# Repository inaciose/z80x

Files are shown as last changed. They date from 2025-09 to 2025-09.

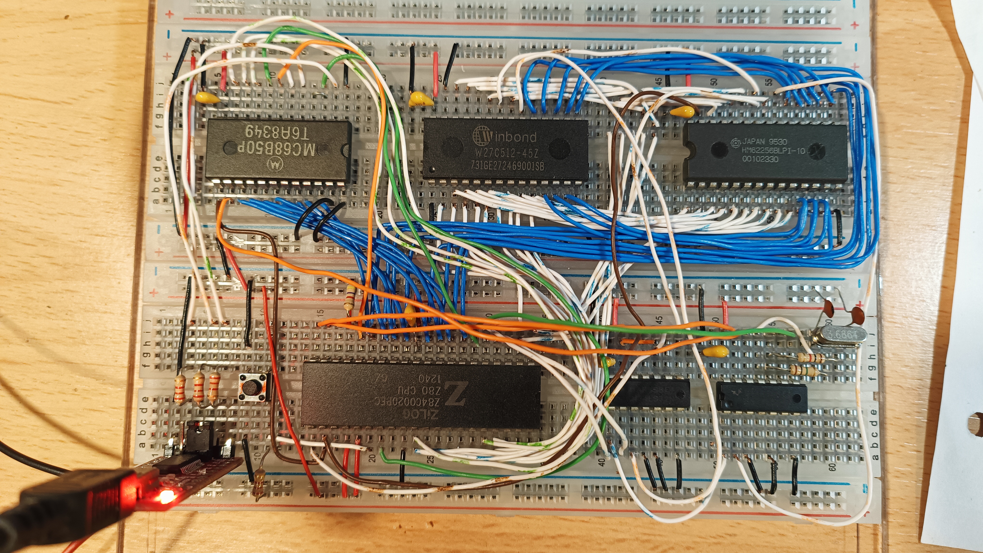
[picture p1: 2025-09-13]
Z80_SBC1/breadboard.jpg

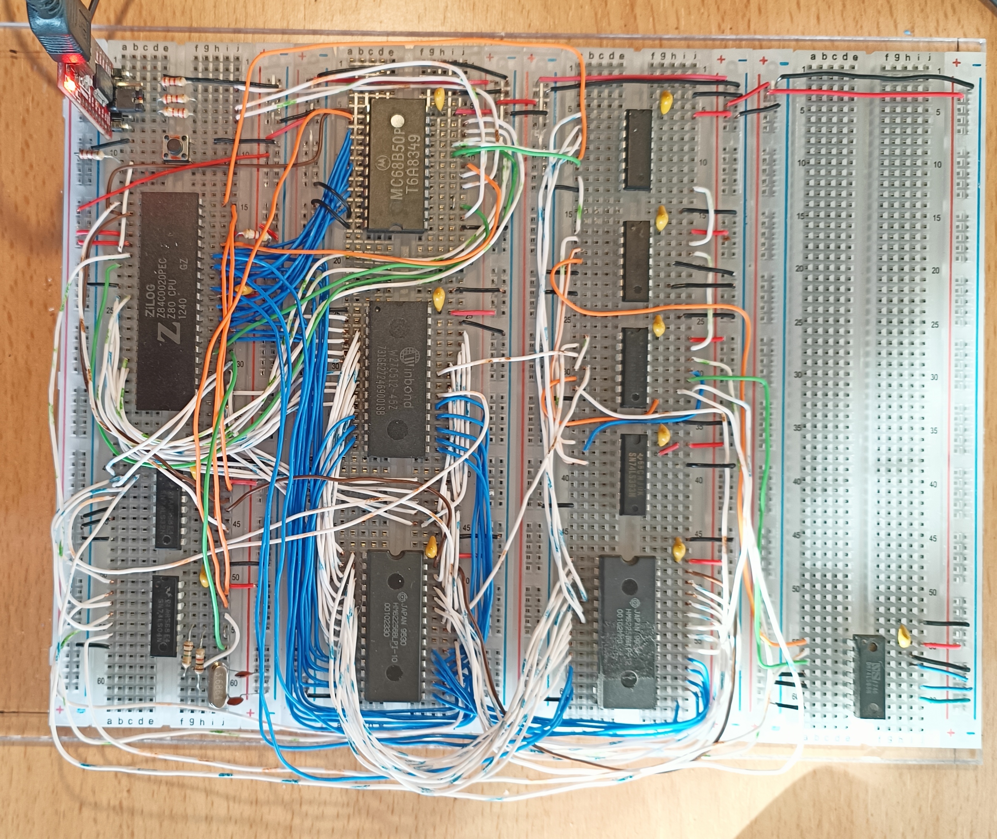
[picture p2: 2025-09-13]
Z80_SBC2/breadboard.jpg

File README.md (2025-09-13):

# z80x
SBCs &amp; MBCs and other Z80 explorations    

# Z80_SBC1
3.6864Mz, 16KB ROM, 32K RAM and serial MC68B50 (0x80) 57600bps (115200 c/ o dobro do relógio)  

ROM 9B000000.BIN with (RC2014 versions):  
- SCM-Small Computer Monitor  
- MS-BASIC  

# Z80_SBC2
3.6864Mz, 16KB (0KB paged) ROM, 48KB (64KB paged) RAM and serial MC68B50 (0x80) 57600bps  
Pageable ROM/RAML16K (0x38 toggle page, 0x30 reset page)  

Same ROM as Z80_SBC1 (or the one with CP/M 2.2 bootloader ?)

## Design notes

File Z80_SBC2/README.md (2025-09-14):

# Z80_SBC2

3.6864Mz, 16KB (0KB paged) ROM, 48KB (64KB paged) RAM and serial MC68B50 (0x80) 57600bps 8N1  
Pageable ROM/RAML16K (0x38 toggle page, 0x30 reset page)  

Same ROM as Z80_SBC1: 9B000000.BIN; (or the one with CP/M 2.2 bootloader ?)  

Press reset after power on (the reset circuit must be revised)
Help (commands): help  
MS-BASIC: G 2000  
Exit MS-BASIC: monitor  

# Page ROM

Copy ROM to RAM  
Load rom2ram.z80.hex file contents    
G 8000  

Toogle PAGE  
o 38 HH  

Reset PAGE  
o 30 HH  

# Equations  
MEMRD = MREQ_ + RD_  
MEMWR = MREQ_ + WR_  

PAGE = Q0 of 74LS393 counter with COUNTER_CLK via port 0x38, and COUNTER_RESET via port 0x30 or RESET  

ROM_CE = A14 + A15  
ROM_OE = PAGE + MEMRD  

RAML_CE = A15  
RAML_OE = A15 + (not(A14) x not(PAGE)) + MEMRD  
RAMH_WE = MEMWR  

RAMH_CE = not(A15)  
RAMH_OE = MEMRD  
RAMH_WE = MEMWR  

# Truth table for RAML_OE  
MR = MEMRD  

M A A P Y  
R 1 1 A  
  5 4 G  
      E  
0 0 0 0 1  
0 0 0 1 0 > MR + A15 + A14 + not(PAGE)  
0 0 1 0 0 > MR + A15 + not(A14) + PAGE  
0 0 1 1 0 > MR + A15 + not(A14) + not(PAGE)  
0 1 0 0 1  
0 1 0 1 1  
0 1 1 0 1  
0 1 1 1 1  
0 0 0 0 1  
0 0 0 1 1  
0 0 1 0 1  
0 0 1 1 1  
0 1 0 0 1  
0 1 0 1 1  
0 1 1 0 1  
0 1 1 1 1  

RAML_OE = (MR + A15 + A14 + not(PAGE)) x (MR + A15 + not(A14) + PAGE) x (MR + A15 + not(A14) + not(PAGE))  

Simplificado, fica: RAML_OE = A15 + (not(A14) x not(PAGE)) + MEMRD  

Com ROM 8K ???:  
ROM_CE = A13 + A14 + A15 (no IC: A15-GND, A14-GND, A13-GND)  
RAML_OE = A15 + (not(A13) x not(PAGE)) + MEMRD  

# Notes
Based on Z80_SBC1, and part of the RC2014 Pageable ROM (74LS138, 74LS393 and its input logic) with some more required logic.  
https://rc2014.co.uk/modules/pageable-rom/

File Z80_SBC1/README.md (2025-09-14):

# Z80_SBC1

3.6864Mz, 16KB ROM, 32K RAM and serial MC68B50 (0x80) 57600bps 8N1 (115200 c/ o dobro do relógio)  

ROM 9B000000.BIN with (RC2014 versions):  
- 0000-1FFF: SCM-Small Computer Monitor  
- 2000-3FFF: MS-BASIC  

Press reset after power on (the reset circuit must be revised)

Help (commands): help  
MS-BASIC: G 2000  
Exit MS-BASIC: monitor  

# Equations  
MEMRD = MREQ_ + RD_  
MEMWR = MREQ_ + WR_  

ROM_CE = A14 + A15  
ROM_OE = MEMRD  

RAM_CE = not(A15)  
RAM_OE = MEMRD  
RAM_WE = MEMWR  

ACIA = A7 x not(A6) (10XX XXXX, 0x80 com replicas, RC2014 MC68B50 serial module)  

# Notes
Based on Searle Grants Minimal Z80 with 8KB ROM, 32K RAM and serial MC68B50.  
http://searle.x10host.com/z80/SimpleZ80_32K.html

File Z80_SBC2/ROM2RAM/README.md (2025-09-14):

# ROM2RAM

Copy the 16KB ROM contents to the first 16KB of RAM (while ROM still paged in).  

In minicom:  
sudo minicom -c on --device /dev/ttyUSB0  

Copy rom2ram.z80.hex contents and past it to SCM prompt  

Wait for:  
*Ready  

*  
then type:  
G 8000  

ROM contents copied to RAM. Now we can toogle ROM (PAGE) in/out by writing to 0x38 or reset PAGE (PAGE=0) by writing to 0x30.  

74LS393:Q0 = PAGE  

PAGE = 0: ROM in, RAMLL out;  
PAGE = 1: ROM out, RAMLL in;  

Toggle PAGE  
o 38 0  

Reset PAGE  
o 30 0  

# Assembler
Assembly for the asm80, the z80 assembler online.  
https://www.asm80.com/

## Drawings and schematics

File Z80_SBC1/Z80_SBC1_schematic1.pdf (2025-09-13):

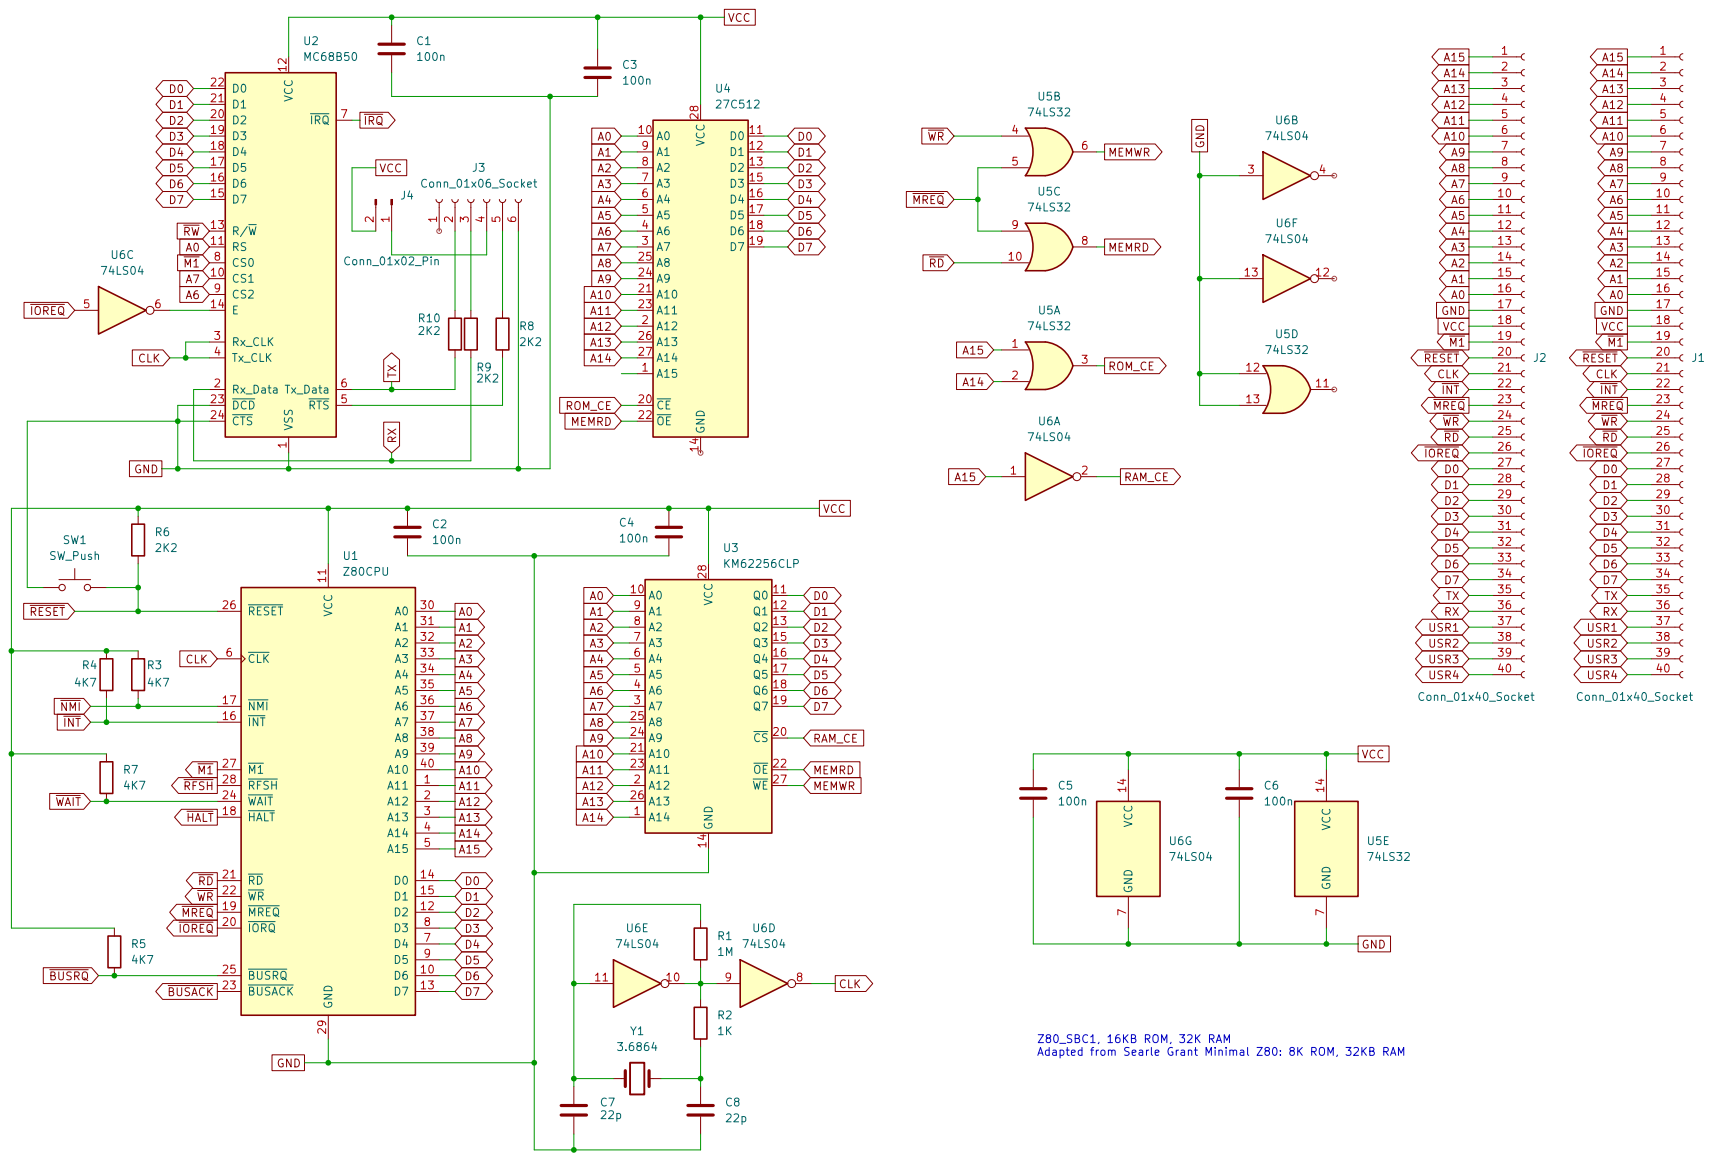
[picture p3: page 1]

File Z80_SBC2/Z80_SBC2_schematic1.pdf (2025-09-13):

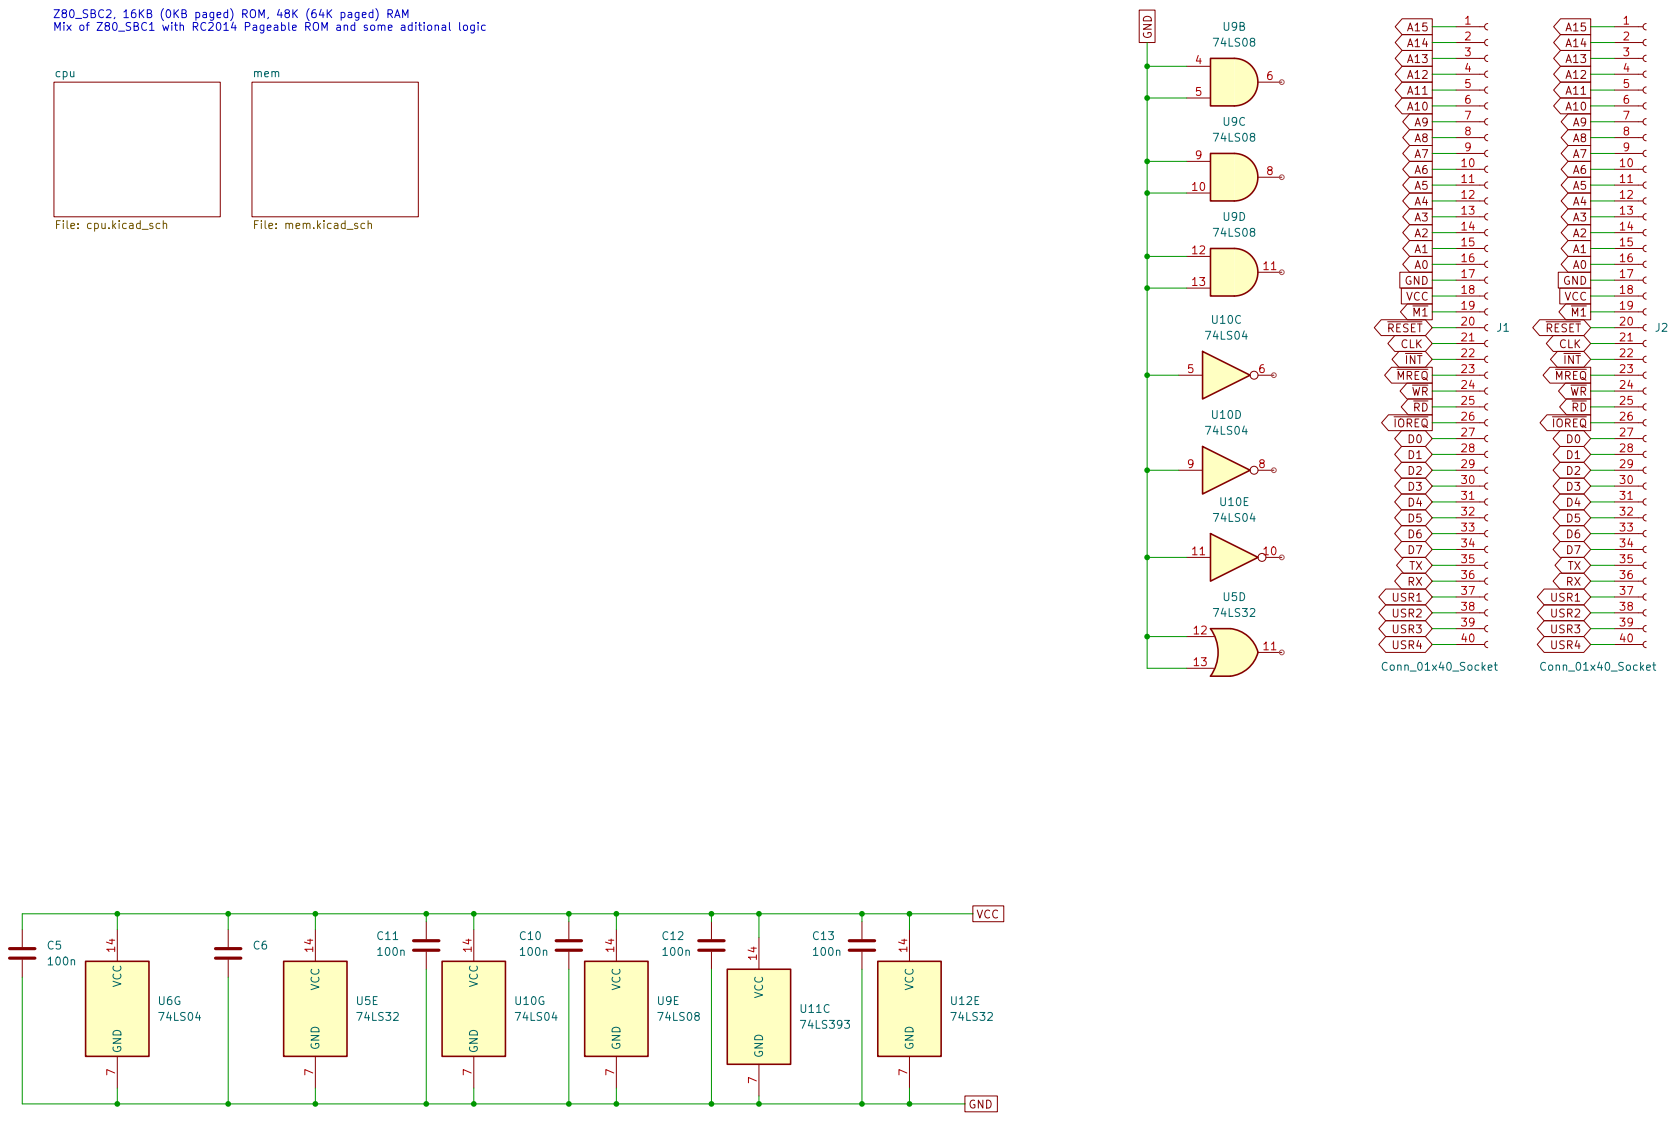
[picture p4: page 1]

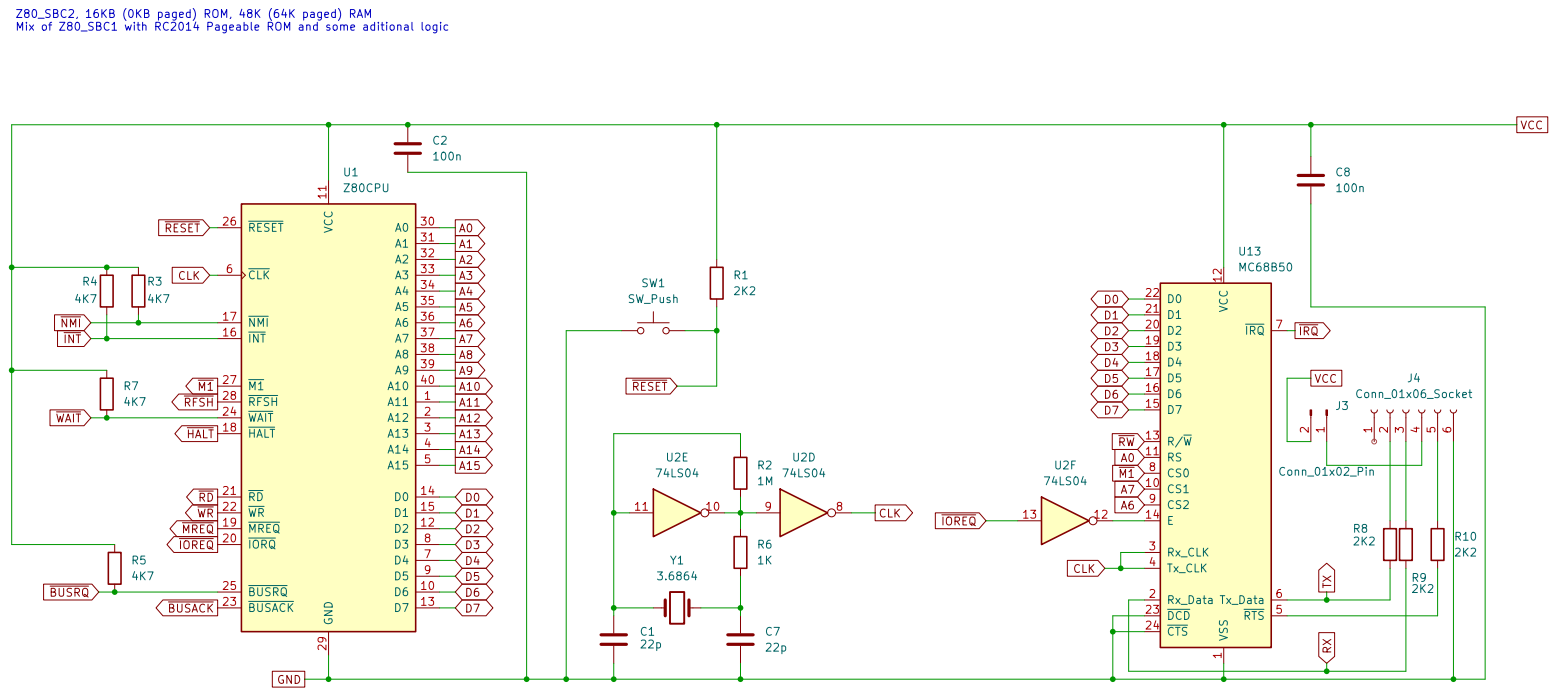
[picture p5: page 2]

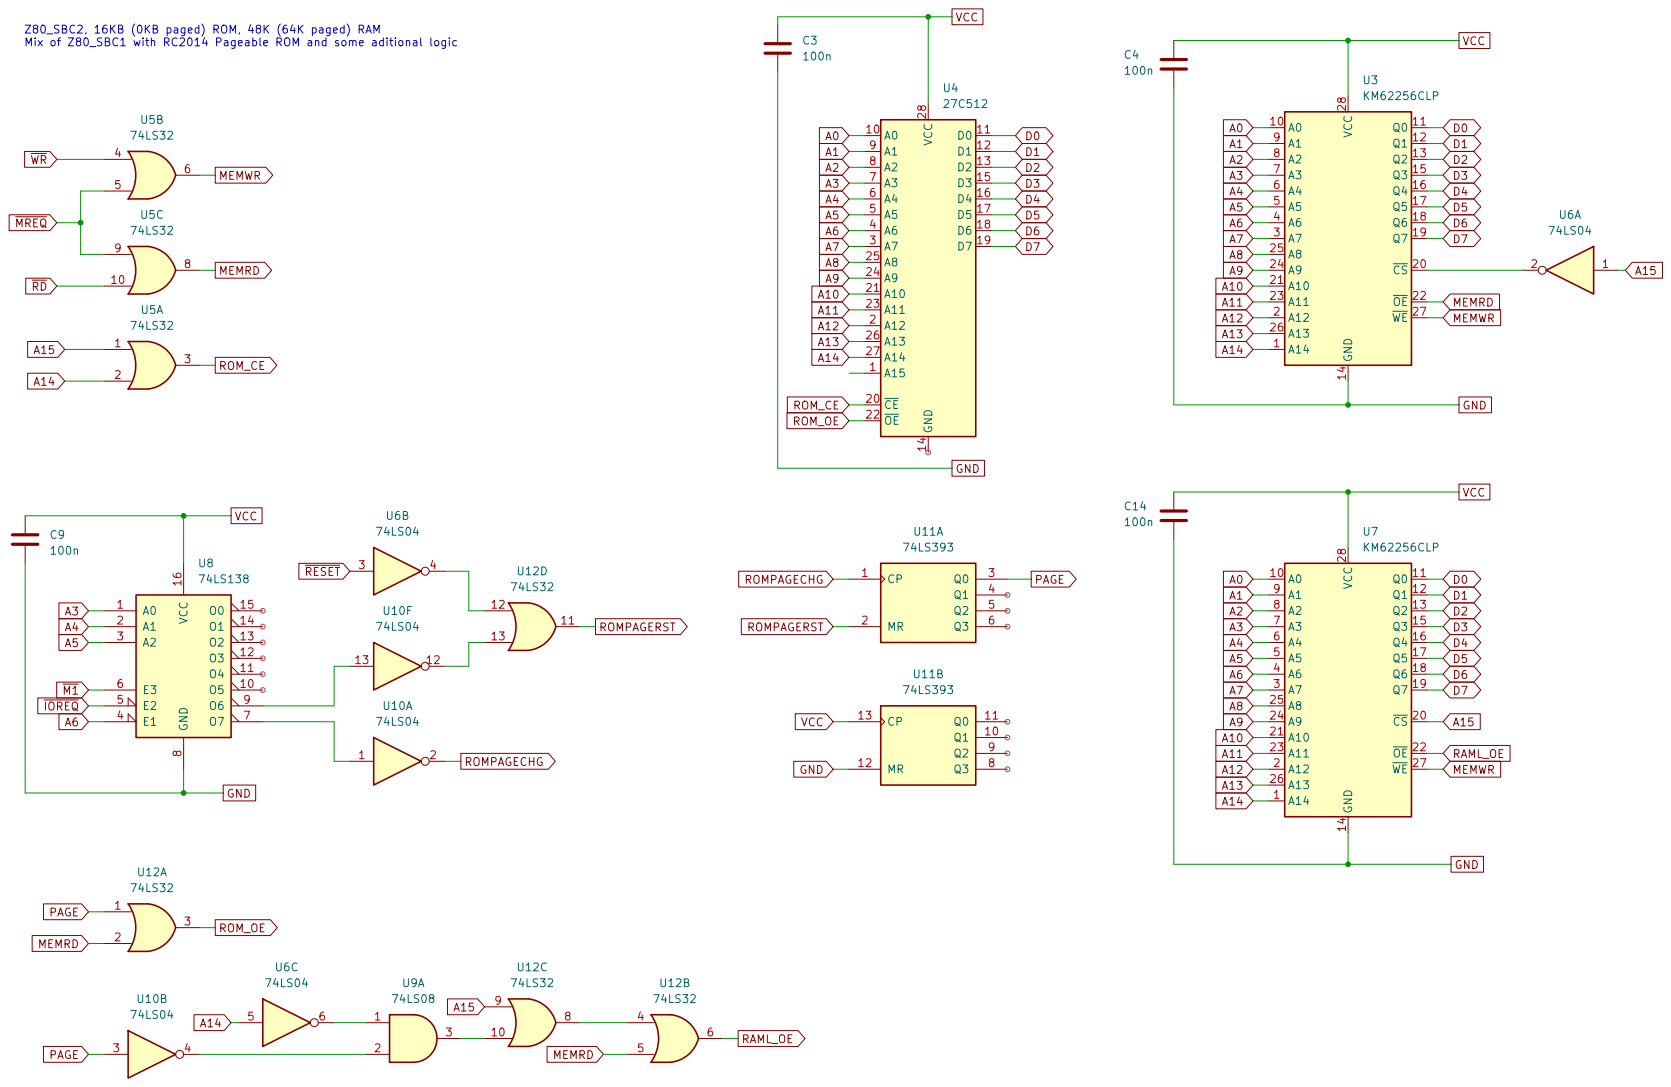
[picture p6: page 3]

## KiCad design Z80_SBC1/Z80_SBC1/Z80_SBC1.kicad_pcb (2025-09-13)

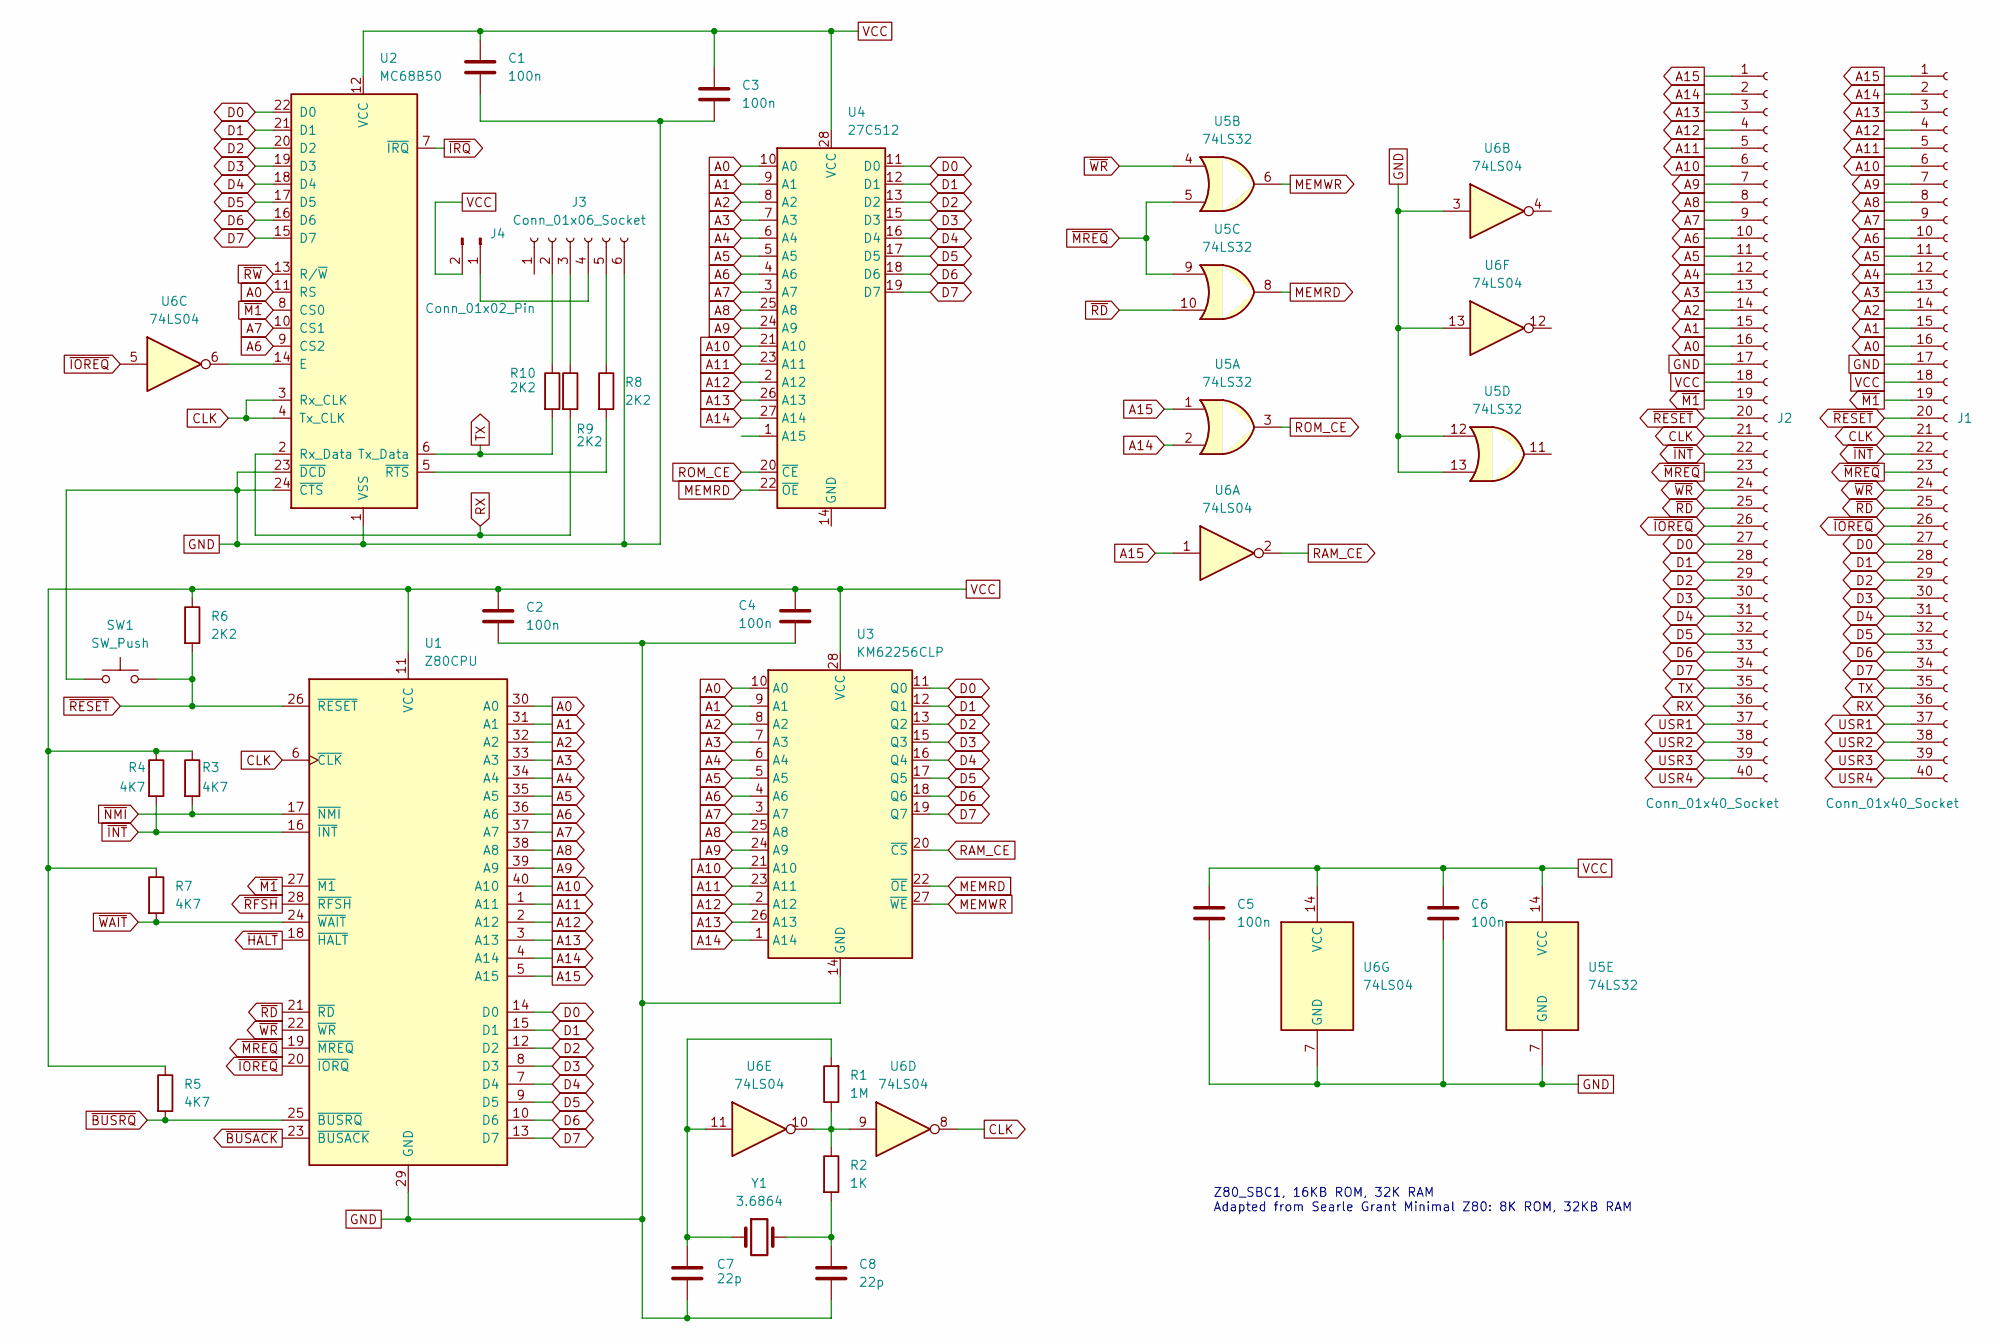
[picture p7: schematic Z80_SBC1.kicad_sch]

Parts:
C1, C2, C3, C4, C5, C6: 100n; C_Disc_D5.1mm_W3.2mm_P5.00mm
C7, C8: 22p; C_Disc_D3.0mm_W2.0mm_P2.50mm
J1: Conn_01x40_Socket; PinHeader_1x40_P2.54mm_Horizontal
J2: Conn_01x40_Socket; PinHeader_1x40_P2.54mm_Vertical
J3: Conn_01x06_Socket; PinHeader_1x06_P2.54mm_Horizontal
J4: Conn_01x02_Pin; PinHeader_1x02_P2.54mm_Vertical
R1: 1M; R_Axial_DIN0207_L6.3mm_D2.5mm_P7.62mm_Horizontal
R2: 1K; R_Axial_DIN0207_L6.3mm_D2.5mm_P7.62mm_Horizontal
R3, R4, R5, R7: 4K7; R_Axial_DIN0207_L6.3mm_D2.5mm_P7.62mm_Horizontal
R6, R8, R9, R10: 2K2; R_Axial_DIN0207_L6.3mm_D2.5mm_P7.62mm_Horizontal
SW1: SW_Push; SW_Tactile_Straight_KSA0Axx1LFTR
U1: Z80CPU; DIP-40_W15.24mm_Socket_LongPads
U2: MC68B50; DIP-24_W15.24mm
U3: KM62256CLP; DIP-28_W15.24mm
U4: 27C512; DIP-28_W15.24mm
U5: 74LS32; DIP-14_W7.62mm_LongPads
U6: 74LS04; DIP-14_W7.62mm_LongPads
Y1: 3.6864; Crystal_HC18-U_Vertical

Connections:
A0: J1.16, J2.16, U1.30 (A0), U2.11 (RS), U3.10 (A0), U4.10 (A0)
A1: J1.15, J2.15, U1.31 (A1), U3.9 (A1), U4.9 (A1)
A2: J1.14, J2.14, U1.32 (A2), U3.8 (A2), U4.8 (A2)
A3: J1.13, J2.13, U1.33 (A3), U3.7 (A3), U4.7 (A3)
A4: J1.12, J2.12, U1.34 (A4), U3.6 (A4), U4.6 (A4)
A5: J1.11, J2.11, U1.35 (A5), U3.5 (A5), U4.5 (A5)
A6: J1.10, J2.10, U1.36 (A6), U2.9 (CS2), U3.4 (A6), U4.4 (A6)
A7: J1.9, J2.9, U1.37 (A7), U2.10 (CS1), U3.3 (A7), U4.3 (A7)
A8: J1.8, J2.8, U1.38 (A8), U3.25 (A8), U4.25 (A8)
A9: J1.7, J2.7, U1.39 (A9), U3.24 (A9), U4.24 (A9)
A10: J1.6, J2.6, U1.40 (A10), U3.21 (A10), U4.21 (A10)
A11: J1.5, J2.5, U1.1 (A11), U3.23 (A11), U4.23 (A11)
A12: J1.4, J2.4, U1.2 (A12), U3.2 (A12), U4.2 (A12)
A13: J1.3, J2.3, U1.3 (A13), U3.26 (A13), U4.26 (A13)
A14: J1.2, J2.2, U1.4 (A14), U3.1 (A14), U4.27 (A14), U5.2
A15: J1.1, J2.1, U1.5 (A15), U5.1, U6.1
CLK: J1.21, J2.21, U1.6 (~CLK), U2.3 (Rx_CLK), U2.4 (Tx_CLK), U6.8
D0: J1.27, J2.27, U1.14 (D0), U2.22 (D0), U3.11 (Q0), U4.11 (D0)
D1: J1.28, J2.28, U1.15 (D1), U2.21 (D1), U3.12 (Q1), U4.12 (D1)
D2: J1.29, J2.29, U1.12 (D2), U2.20 (D2), U3.13 (Q2), U4.13 (D2)
D3: J1.30, J2.30, U1.8 (D3), U2.19 (D3), U3.15 (Q3), U4.15 (D3)
D4: J1.31, J2.31, U1.7 (D4), U2.18 (D4), U3.16 (Q4), U4.16 (D4)
D5: J1.32, J2.32, U1.9 (D5), U2.17 (D5), U3.17 (Q5), U4.17 (D5)
D6: J1.33, J2.33, U1.10 (D6), U2.16 (D6), U3.18 (Q6), U4.18 (D6)
D7: J1.34, J2.34, U1.13 (D7), U2.15 (D7), U3.19 (Q7), U4.19 (D7)
GND: C1.2, C2.2, C3.2, C4.2, C5.2, C6.2, C7.2, C8.2, J1.17, J2.17, J3.6, SW1.1, U1.29 (GND), U2.1 (VSS), U2.23 (~DCD), U2.24 (~CTS), U3.14 (GND), U5.7 (GND), U5.12, U5.13, U6.3, U6.7 (GND), U6.13
MEMRD: U3.22 (~OE), U4.22 (~OE), U5.8
MEMWR: U3.27 (~WE), U5.6
unnamed: C7.1, R1.2, U6.11, Y1.1
unnamed: C8.1, R2.2, Y1.2
unnamed: J3.2, R10.1
unnamed: J3.3, R9.1
unnamed: J3.4, J4.1
unnamed: J3.5, R8.1
unnamed: R1.1, R2.1, U6.9, U6.10
unnamed: U2.14 (E), U6.6
unnamed: R8.2, U2.5 (~RTS)
RAM_CE: U3.20 (~CS), U6.2
ROM_CE: U4.20 (~CE), U5.3
RX: J1.36, J2.36, R9.2, U2.2 (Rx_Data)
TX: J1.35, J2.35, R10.2, U2.6 (Tx_Data)
USR1: J1.37, J2.37
USR2: J1.38, J2.38
USR3: J1.39, J2.39
USR4: J1.40, J2.40
VCC: C1.1, C2.1, C3.1, C4.1, C5.1, C6.1, J1.18, J2.18, J4.2, R3.1, R4.1, R5.1, R6.1, R7.1, U1.11 (VCC), U2.12 (VCC), U3.28 (VCC), U4.28 (VCC), U5.14 (VCC), U6.14 (VCC)
~BUSACK: U1.23 (~BUSACK)
~BUSRQ: R5.2, U1.25 (~BUSRQ)
~HALT: U1.18 (~HALT)
~INT: J1.22, J2.22, R4.2, U1.16 (~INT)
~IOREQ: J1.26, J2.26, U1.20 (~IORQ), U6.5
~IRQ: U2.7 (~IRQ)
~M1: J1.19, J2.19, U1.27 (~M1), U2.8 (CS0)
~MREQ: J1.23, J2.23, U1.19 (~MREQ), U5.5, U5.9
~NMI: R3.2, U1.17 (~NMI)
~RD: J1.25, J2.25, U1.21 (~RD), U5.10
~RESET: J1.20, J2.20, R6.2, SW1.2, U1.26 (~RESET)
~RFSH: U1.28 (~RFSH)
~RW: U2.13 (R/~W)
~WAIT: R7.2, U1.24 (~WAIT)
~WR: J1.24, J2.24, U1.22 (~WR), U5.4

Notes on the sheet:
Z80_SBC1, 16KB ROM, 32K RAM Adapted from Searle Grant Minimal Z80: 8K ROM, 32KB RAM

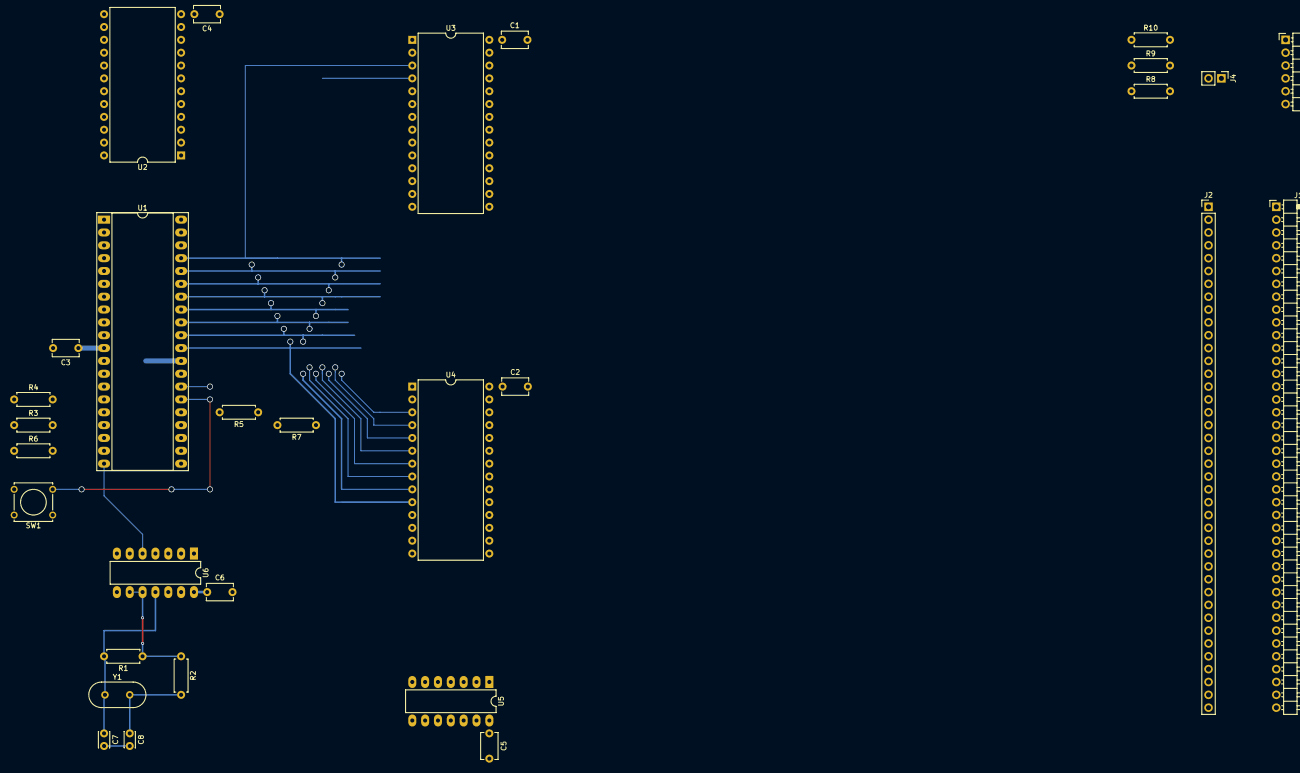
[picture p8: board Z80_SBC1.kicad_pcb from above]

Board: 2 copper layers, 30 parts (0 on the bottom side), 56 nets.
